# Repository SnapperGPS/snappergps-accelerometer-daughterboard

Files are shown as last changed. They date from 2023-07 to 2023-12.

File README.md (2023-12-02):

# snappergps-accelerometer-daughterboard

*Author: Jonas Beuchert*

Accelerometer daughterboard for a basic SnapperGPS receiver.

## Table of contents

* [Files](#files)
* [Manufacturing](#manufacturing)
* [Components](#components)
* [Assembly](#assembly)
* [Flashing](#flashing)
* [Usage](#usage)
* [Acknowledgements](#acknowledgements)

## Files

* `accelerometer-daughterboard.brd`: PCB layout file for the daughterboard. Created with Autodesk Eagle.
* `accelerometer-daughterboard`: Schematic file for the daughterboard. Created with Autodesk Eagle.
* `CAMOutputs`: Gerber files and drill file for manufacturing the daughterboard.
* `accelerometer-daughterboard.mnt` and `accelerometer-daughterboard.mnb`: Centroid files (top and bottom) for assembly.

## Manufacturing

* Get some PCBs manufactured by a PCB manufacturer of your choice.
(I used [Aisler](https://aisler.net/) or [PCBWay](https://www.pcbway.com/) in the past.)
For this, upload the `.brd` file or the `CAMOutputs` folder to the manufacturer's website.
Choose a two-layered PCB with size 3.74 mm x 11.94 mm.

* If you want, you can also let the manufacturer assemble the board(s) for you.

## Components

* 2x 10 kOhm resistor (footprint 0603), e.g., [RK73H1JTTD1002F](https://octopart.com/rk73h1jttd1002f-koa+speer-2166376).
* 1x [LIS3DH](https://www.st.com/en/mems-and-sensors/lis3dh.html) 3-axis MEMS accelerometer.

## Assembly

* Solder the two resistors and the accelerometer on the daughterboard.
Ensure that the pin-1 dot on the accelerometer is aligned with the dot on the PCB.
I recommend solder paste and a hot plate (or hot air gun) for soldering.

* Solder the assembled daughterboard on a basic SnapperGPS receiver.
The five pads on the back of the daughterboard should connect to the five pads on the SnapperGPS receiver.
The pads labeled `VDD` shall align.

## Flashing

* Go to [https://snappergps.info/flash](https://snappergps.info/flash).
* Connect the SnapperGPS receiver to your computer via USB.
* Pair the SnapperGPS receiver.
* Select the `SnapperGPS-Accelerometer` firmware.
* Flash the firmware.

## Usage

Find instructions in [the firmware repository](https://github.com/SnapperGPS/snappergps-firmware/blob/main/firmware_versions/snapper-accelerometer/README.md).

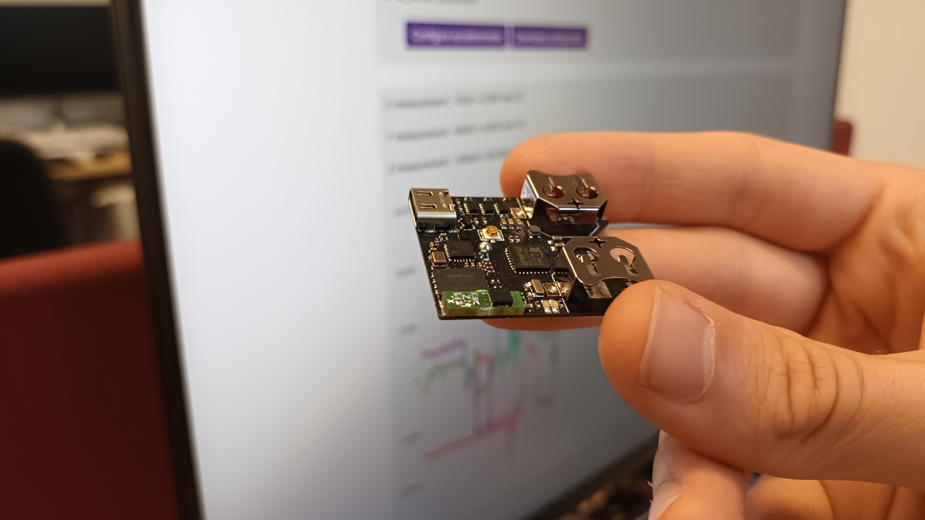
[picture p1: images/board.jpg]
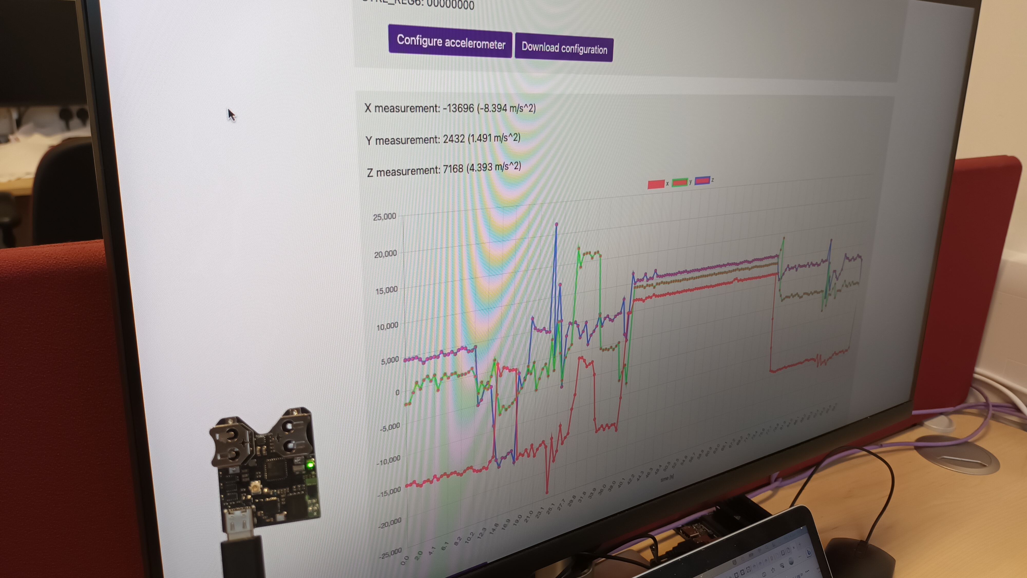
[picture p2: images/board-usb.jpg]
|   | 
|:--:| 
| *Figures 1 & 2: SnapperGPS V2.0.0 with accelerometer daughterboard.* |

## Acknowledgements

This SnapperGPS daughter-board was developed by
[Jonas Beuchert](https://users.ox.ac.uk/~kell5462/)
in the Department of Computer Science
of the University of Oxford.

Jonas Beuchert is
funded by the EPSRC Centre for Doctoral Training in
Autonomous Intelligent Machines and Systems
(DFT00350-DF03.01) and develops
SnapperGPS as part of his doctoral studies.
The implementation of SnapperGPS 
was co-funded by an EPSRC IAA Technology Fund
(D4D00010-BL14).

Parts of the design are based on the [Adafruit LIS3DH Triple-Axis Accelerometer (+-2g/4g/8g/16g) PCB](https://github.com/adafruit/Adafruit-LIS3DH-Breakout-PCB), e.g., footprints.
It was designed by Limor Fried/Ladyada for Adafruit Industries.
Find the original readme [here](adafruit-readme.md).

This repository is licensed under a
[Creative Commons Attribution 3.0 International License][cc-by].

[][cc-by]

[cc-by]: http://creativecommons.org/licenses/by/3.0/
[cc-by-image]: https://i.creativecommons.org/l/by/3.0/88x31.png

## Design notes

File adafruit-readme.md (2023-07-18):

## Adafruit LIS3DH Triple-Axis Accelerometer (+-2g/4g/8g/16g) PCB

The LIS3DH is a very popular low power triple-axis accelerometer. It's low-cost, but has just about every 'extra' you'd want in an accelerometer:

3.3V regulator + level shifting, so you can safely use with any Arduino or microcontroller without the need for an external level shifter!
We kept seeing this accelerometer in teardowns of commercial products and figured that if it's the most-commonly used accelerometer, its worth having a breakout board!

This sensor communicates over I2C or SPI (our library code supports both) so you can share it with a bunch of other sensors on the same I2C bus. There's an address selection pin so you can have two accelerometers share an I2C bus.

To get you going fast, we spun up a custom made PCB in the STEMMA QT form factor, making them easy to interface with. The STEMMA QT connectors on either side are compatible with the SparkFun Qwiic I2C connectors. This allows you to make solderless connections between your development board and the LIS331s or to chain them with a wide range of other sensors and accessories using a compatible cable. We’ve of course broken out all the pins to standard headers and added a voltage regulator and level shifting so allow you to use it with either 3.3V or 5V systems such as the Raspberry Pi + Feather series or Arduino Uno respectively.

PCB files for the Adafruit LIS3DH Breakout. The format is EagleCAD schematic and board layout
- https://www.adafruit.com/product/2809

### License

Adafruit invests time and resources providing this open source design, please support Adafruit and open-source hardware by purchasing products from [Adafruit](https://www.adafruit.com)!

All text above must be included in any redistribution

Designed by Limor Fried/Ladyada for Adafruit Industries.
Creative Commons Attribution/Share-Alike, all text above must be included in any redistribution. 
See license.txt for additional information.

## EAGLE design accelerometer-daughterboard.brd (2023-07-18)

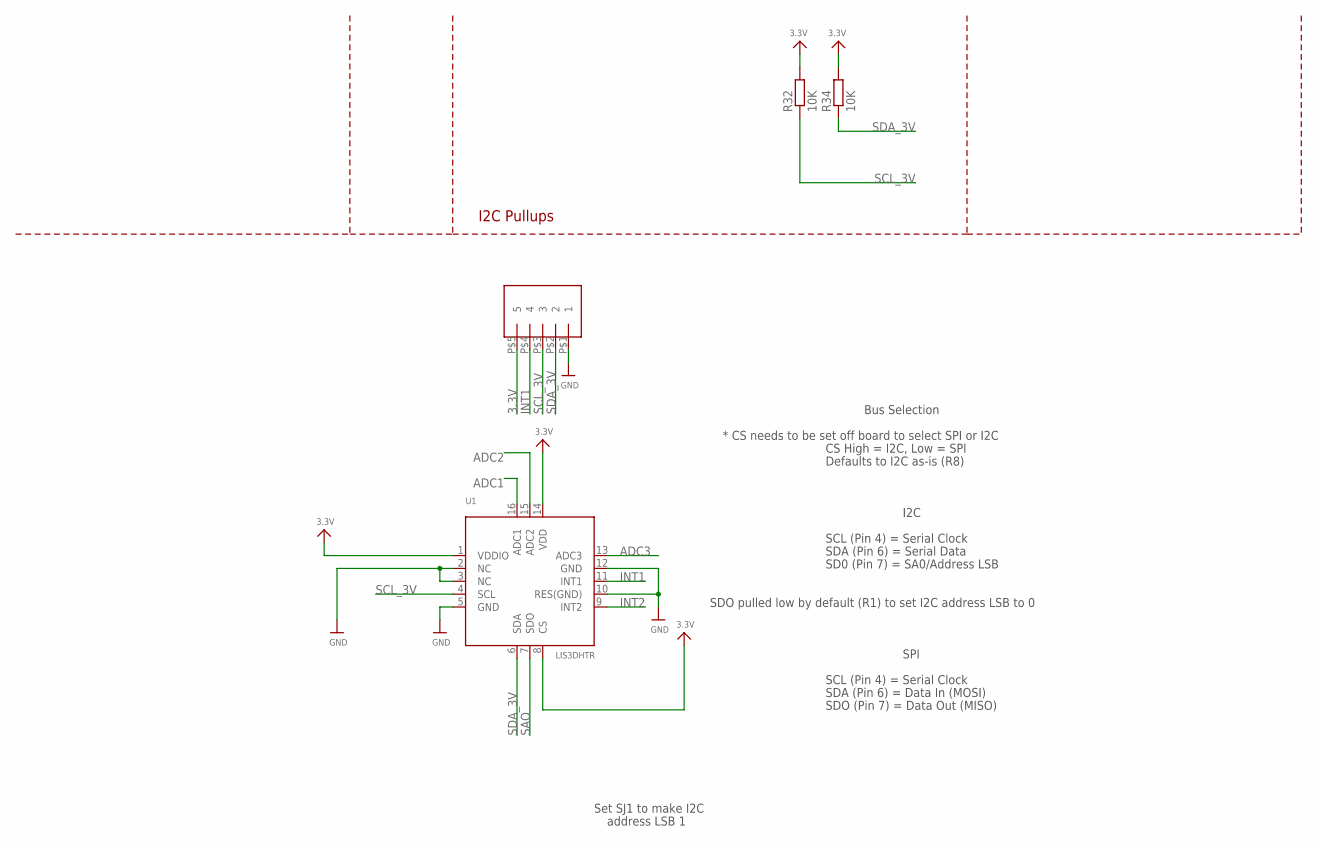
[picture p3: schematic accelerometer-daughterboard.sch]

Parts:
R32, R34: 10K; R0603
U1: LIS3DHTR; LGA16_3X3MM
U$1: ALEX_CONN5

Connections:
3.3V: R32.2, R34.2, U1.1 (VDDIO), U1.8 (CS), U1.14 (VDD), U$1.P$5 (5)
ADC1: U1.16 (ADC1)
ADC2: U1.15 (ADC2)
ADC3: U1.13 (ADC3)
GND: U1.2 (NC), U1.3 (NC), U1.5 (GND), U1.10 (RES(GND)), U1.12 (GND), U$1.P$1 (1)
INT1: U1.11 (INT1), U$1.P$4 (4)
INT2: U1.9 (INT2)
SAO: U1.7 (SDO)
SCL_3V: R32.1, U1.4 (SCL), U$1.P$3 (3)
SDA_3V: R34.1, U1.6 (SDA), U$1.P$2 (2)

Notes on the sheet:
I2C Pullups
I2C
SCL (Pin 4) = Serial Clock
SDA (Pin 6) = Serial Data
SD0 (Pin 7) = SA0/Address LSB
* CS needs to be set off board to select SPI or I2C
CS High = I2C, Low = SPI
Defaults to I2C as-is (R8)
SDO pulled low by default (R1) to set I2C address LSB to 0
Bus Selection
SPI
SDA (Pin 6) = Data In (MOSI)
SDO (Pin 7) = Data Out (MISO)
Set SJ1 to make I2C
address LSB 1

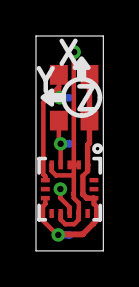
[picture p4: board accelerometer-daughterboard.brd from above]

Board: 2 copper layers, 3.7 x 11.9 mm, 4 parts (1 on the bottom side), 5 nets.

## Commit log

2023-06-26 Add initial files
    [accelerometer-daughterboard.brd, accelerometer-daughterboard.sch]
2023-06-26 Remove power supply (have 3.3 V already)
    [accelerometer-daughterboard.brd, accelerometer-daughterboard.sch]
2023-06-26 Remove LED
    [accelerometer-daughterboard.brd, accelerometer-daughterboard.sch]
2023-06-26 Remove I2C level-shifting
    [accelerometer-daughterboard.brd, accelerometer-daughterboard.sch]
2023-06-26 Remove connector headers
    [accelerometer-daughterboard.brd, accelerometer-daughterboard.sch]
2023-06-26 Remove through-holes
    [accelerometer-daughterboard.brd, accelerometer-daughterboard.sch]
2023-06-26 Hardwire CS to I2C mode; add pads; remove un-used board elements
    [accelerometer-daughterboard.brd, accelerometer-daughterboard.sch]
2023-06-26 USe 0603 resistors
    [accelerometer-daughterboard.brd, accelerometer-daughterboard.sch]
2023-06-26 Add vias; remove some wires
    [accelerometer-daughterboard.brd, accelerometer-daughterboard.sch]
2023-06-26 Complete first board draft, including outline and wiring
    [accelerometer-daughterboard.brd, accelerometer-daughterboard.sch]
2023-06-26 Rename SD0 to SA0; add measures
    [accelerometer-daughterboard.brd, accelerometer-daughterboard.sch]
2023-06-26 Change measures layer
    [accelerometer-daughterboard.brd]
2023-06-28 Re-add buffer caps
    [accelerometer-daughterboard.brd, accelerometer-daughterboard.sch]
2023-06-28 remove caps again
    [accelerometer-daughterboard.brd, accelerometer-daughterboard.sch]
2023-06-28 Remove logo
    [accelerometer-daughterboard.sch]
2023-06-28 Change attribute
    [accelerometer-daughterboard.sch]
2023-07-18 Add gerber files and drill files
    [accelerometer-daughterboard.brd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]
2023-12-02 Add centroid files for assembly

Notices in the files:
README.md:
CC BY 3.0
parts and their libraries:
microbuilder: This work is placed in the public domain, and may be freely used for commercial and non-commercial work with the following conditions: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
